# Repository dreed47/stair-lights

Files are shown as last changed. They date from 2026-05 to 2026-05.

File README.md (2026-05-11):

# Smart Staircase Lighting

DIY staircase lighting with capacitive touch detection and Home Assistant integration. Touch the handrail → lights fade in. Walk away → lights fade out. All settings tunable live via HA sliders.

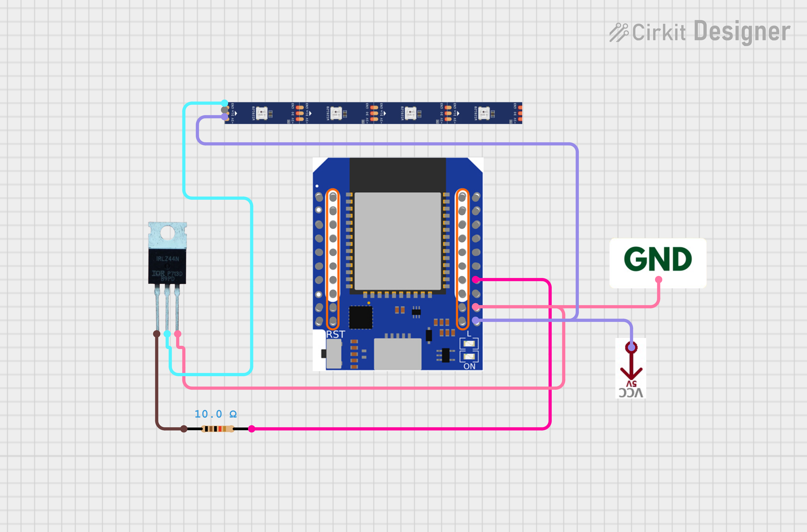
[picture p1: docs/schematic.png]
Wiring Schematic


---

## How It Works

1. Copper tape runs along the underside of the handrail, wired to **GPIO1** on the ESP32-S2 Mini as a capacitive touch sensor.
2. Touch triggers `handle_stair_timer` — a configurable filter-on delay confirms it's a real touch (not noise).
3. **GPIO18** drives an **IRLZ44N MOSFET** via PWM, which powers a **COB LED strip** with a smooth 1-second fade-in.
4. After the configured duration, lights fade out over 4 seconds.
5. Touching again during the timer restarts it (script `mode: restart`).

The COB strip gives a seamless "dot-less" glow. All wiring is routed internally through the wall with low-profile silicone grommets — hardware stays invisible.

---

## Hardware

| Component | Details |
| --- | --- |
| MCU | Wemos S2 Mini (ESP32-S2) |
| MOSFET | IRLZ44N (logic-level, TO-220) |
| LED Strip | COB (chip-on-board), single color |
| Touch Sensor | Copper tape on handrail → GPIO1 |
| PWM Output | GPIO18 → MOSFET gate |
| PCB | Custom KiCad design (see `hardware/kicad/`) |

ESP32-S2 Mini front
ESP32-S2 Mini pinout

---

## Firmware

Built with [ESPHome](https://esphome.io). No custom C++ — pure YAML.

### Flash

```bash
# Install ESPHome if needed
pip install esphome

# Add WiFi credentials
cp firmware/secrets.yaml.example firmware/secrets.yaml
# edit firmware/secrets.yaml with your SSID and password

# Flash
esphome run firmware/stairlights.yaml
```

`secrets.yaml` format:

```yaml
wifi_ssid: "YourNetwork"
wifi_password: "YourPassword"
```

After first flash, OTA updates work over WiFi — no USB needed.

---

## Home Assistant Controls

Once the ESPHome integration is added in HA, five sliders appear:

| Slider | Range | Default | Purpose |
| --- | --- | --- | --- |
| **Light Duration** | 5–120 s | 30 s | How long lights stay on after touch |
| **LED Brightness** | 10–100 % | 100 % | Peak brightness at fade-in |
| **Touch Threshold** | 1,000–300,000 | 50,000 | Capacitive trigger level — tune for your handrail |
| **Touch Filter On** | 0–100 ms | 8 ms | Debounce delay before turning on (rejects noise) |
| **Touch Filter Off** | 0–100 ms | 50 ms | Extra hang time before starting fade-out |

**Calibrating touch sensitivity:** Start with Touch Threshold at 50,000. Watch the `Staircase Touch Pad` binary sensor in HA. Raise the threshold if lights trigger from ambient noise/humidity; lower it if touches aren't registering.

---

## Wiring

See `docs/schematic.png` for the full Cirkit Designer diagram. Key connections:

```text
ESP32-S2 GPIO18  →  IRLZ44N Gate (via 10Ω resistor)
IRLZ44N Drain   →  LED Strip negative
LED Strip +     →  12V supply
IRLZ44N Source  →  GND
ESP32-S2 GPIO1  →  Copper tape (touch sensor)
ESP32-S2 GND   →  GND
ESP32-S2 3.3V  →  (internal, no external connection needed)
```

---

## File Structure

```text
stair-lights/
├── firmware/
│   └── stairlights.yaml        # ESPHome configuration
├── hardware/
│   ├── kicad/                  # KiCad schematic and PCB layout
│   │   ├── StairLights.kicad_pcb
│   │   ├── StairLights.kicad_pro
│   │   ├── StairLights.kicad_prl
│   │   └── StairLights.kicad_sch
│   ├── gerbers/
│   │   └── StairLights.kicad_pcb.zip   # Fabrication-ready Gerbers
│   └── stairs-pcb.step         # 3D model
└── docs/
    ├── schematic.png            # Wiring diagram
    ├── esp32-s2-mini-front.png  # MCU reference photo
    └── esp32-s2-mini-back.png   # MCU pinout
```

---

## Troubleshooting

**Lights trigger randomly** — Capacitive drift from humidity or power fluctuations. Raise Touch Threshold or increase Touch Filter On delay.

**Touch not registering** — Lower Touch Threshold. Ensure copper tape has good contact with the GPIO1 wire.

**Fallback AP** — If WiFi is unreachable, the ESP32 broadcasts `Stairlights Fallback Hotspot`. Connect to it and navigate to `192.168.4.1` to reconfigure.

**OTA fails** — Make sure `secrets.yaml` OTA password matches what was flashed. Default is in the YAML.

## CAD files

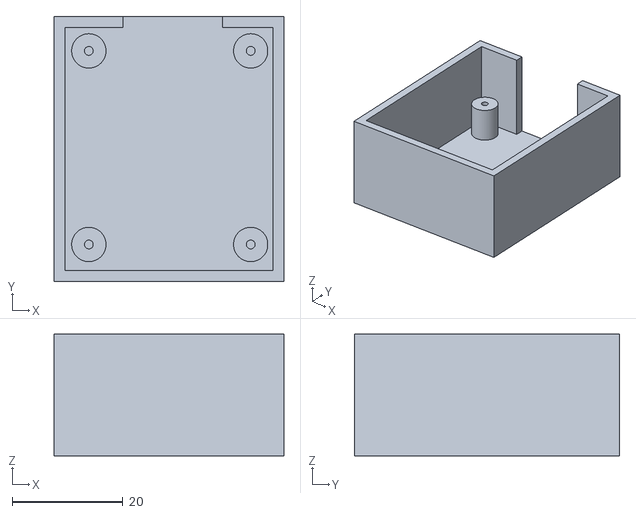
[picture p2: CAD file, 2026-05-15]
hardware/case-bottom.stl
41.5 x 47.9 x 22.0

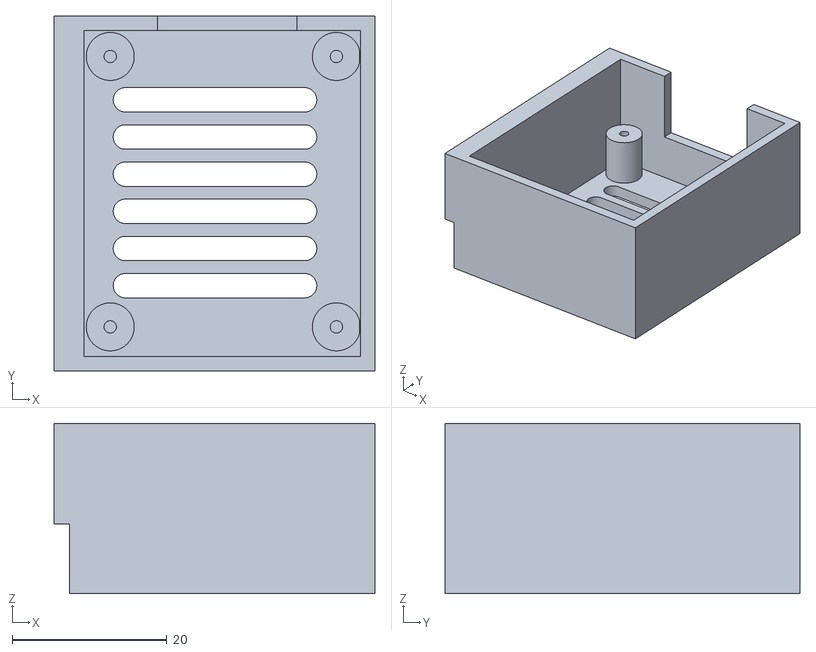
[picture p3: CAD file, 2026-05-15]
hardware/base.stl
41.4 x 45.9 x 22.0

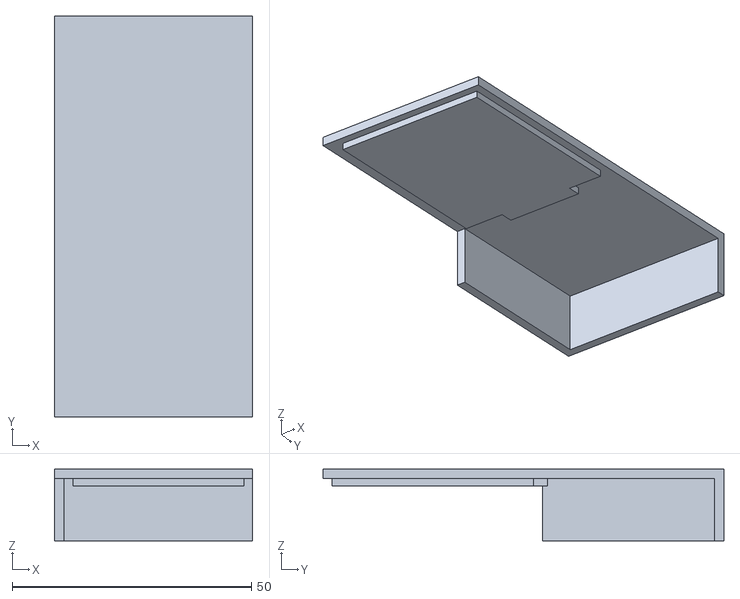
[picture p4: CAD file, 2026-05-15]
hardware/lid.stl
41.4 x 83.9 x 15.0

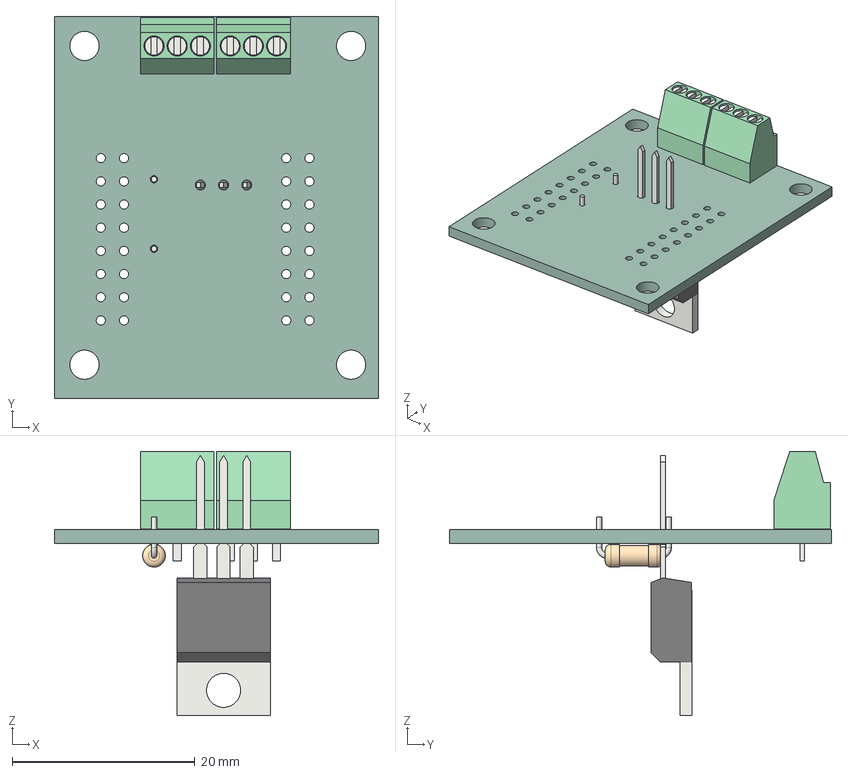
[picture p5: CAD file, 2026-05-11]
hardware/stairs-pcb.step
35.5 x 41.9 x 29.0 mm
TerminalBlock_Phoenix_MPT-0,5-3-2.54_1x03_P2.54mm_Horizontal x 2
TO-220-3_Vertical
R_Axial_DIN0207_L6.3mm_D2.5mm_P7.62mm_Horizontal
StairLights_PCB

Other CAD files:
hardware/base v2.stl

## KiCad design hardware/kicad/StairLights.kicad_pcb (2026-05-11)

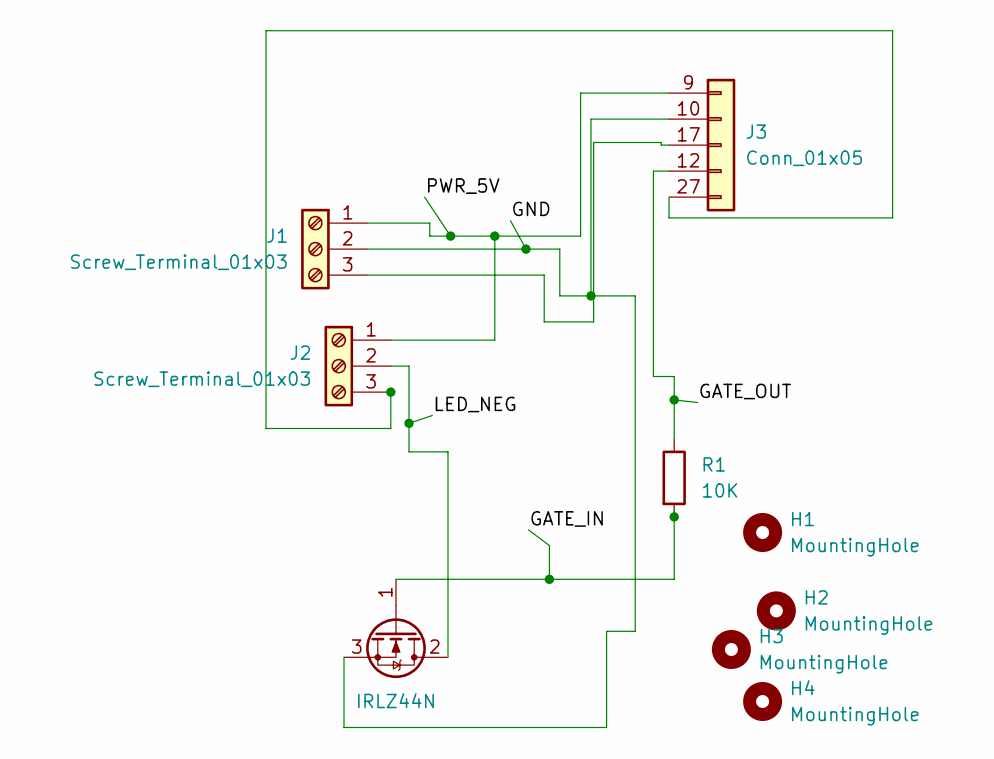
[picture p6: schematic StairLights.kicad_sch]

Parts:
H1, H2, H3, H4: MountingHole; MountingHole_3.2mm_M3
J1, J2: Screw_Terminal_01x03; TerminalBlock_Phoenix_MPT-0,5-3-2.54_1x03_P2.54mm_Horizontal
J3: Conn_01x05; wemoss2
Q1: IRLZ44N; TO-220-3_Vertical
R1: 10K; R_Axial_DIN0207_L6.3mm_D2.5mm_P7.62mm_Horizontal

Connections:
/GATE_IN: Q1.1 (G), R1.2
/GATE_OUT: J3.12, R1.1
/GND: J1.2, J3.10, Q1.3 (S)
/LED_NEG: J2.2, Q1.2 (D)
/PWR_5V: J1.1, J2.1, J3.9
unnamed: J1.3, J3.17
unnamed: J2.3, J3.27

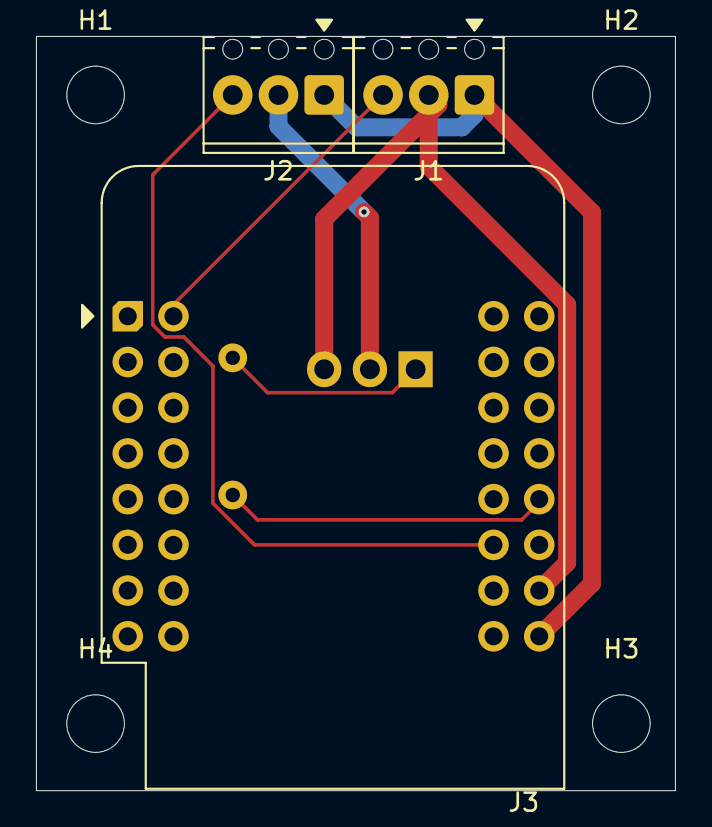
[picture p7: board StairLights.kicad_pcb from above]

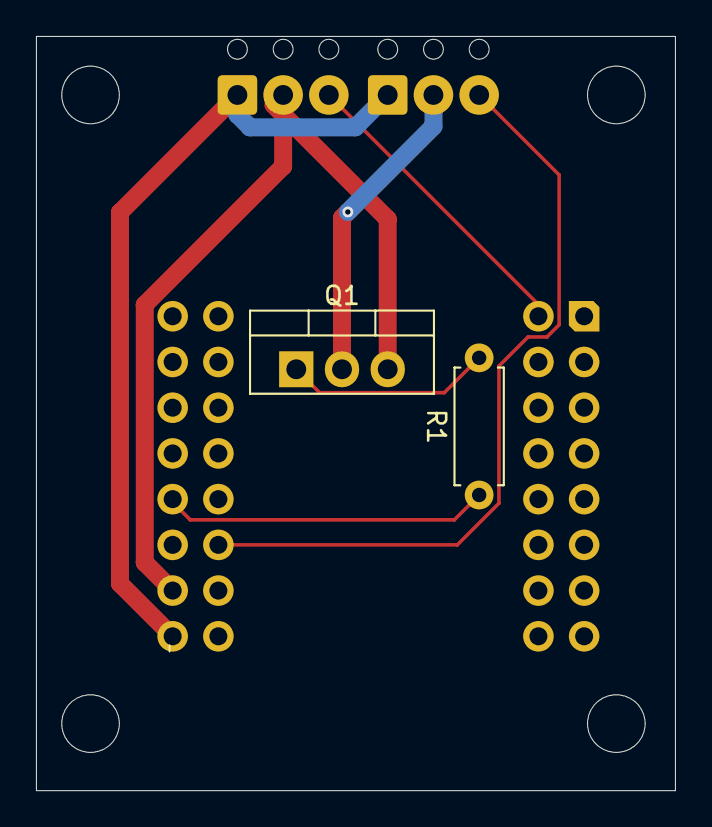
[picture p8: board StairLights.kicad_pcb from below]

Board: 2 copper layers, 35.5 x 41.9 mm, 9 parts (2 on the bottom side), 7 nets.

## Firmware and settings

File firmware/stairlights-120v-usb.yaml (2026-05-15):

globals:
  - id: last_touch_time
    type: unsigned long
    initial_value: '0'
    restore_value: no
  - id: touch_cooldown_ms
    type: int
    initial_value: '6000'  # 6 second cooldown - covers the full power bounce
    restore_value: no

esphome:
  name: stairlights
  friendly_name: StairLights

esp32:
  board: lolin_s2_mini
  framework:
    type: arduino

esp32_touch:
  setup_mode: false
  measurement_duration: 1ms   
  sleep_duration: 0.5ms     
  

logger:
  level: INFO
  #logs:
  #  esp32_touch: ERROR

api:
  encryption:
    key: "APZrHqoNUsUds0Yg1z2ZE0pQV3Ka5jZInQDgnXsFt8E="

ota:
  - platform: esphome
    password: "c4cd1166b0949847f0890fbffeeb403f"

wifi:
  ssid: !secret wifi_ssid
  password: !secret wifi_password
  ap:
    ssid: "Stairlights Fallback Hotspot"
    password: "02FUenUi5wo2"

captive_portal: 

# ============================================================
# HOME ASSISTANT CONTROLLABLE SETTINGS
# ============================================================

number:
  - platform: template
    name: "Staircase Light Duration"
    id: light_duration
    icon: "mdi:timer-outline"
    unit_of_measurement: "seconds"
    min_value: 5
    max_value: 120
    step: 5
    initial_value: 30
    optimistic: true
    restore_value: true
    mode: slider

  - platform: template
    name: "Staircase LED Brightness"
    id: led_brightness
    icon: "mdi:brightness-5"
    unit_of_measurement: "%"
    min_value: 10
    max_value: 100
    step: 5
    initial_value: 100
    optimistic: true
    restore_value: true
    mode: slider

  - platform: template
    name: "Touch Threshold"
    id: touch_threshold_ui
    icon: "mdi:target-variant"
    min_value: 10000
    max_value: 500000      
    step: 5000
    initial_value: 180000  # Hardcoded default above the 149k power bounce
    optimistic: true
    mode: slider      
    on_value:
      then:
        - lambda: 'id(stair_touch).set_threshold(x);'


  - platform: template
    name: "Touch Filter On"
    id: touch_filter_on
    icon: "mdi:clock-start"
    unit_of_measurement: "ms"
    min_value: 0
    max_value: 100
    step: 1
    initial_value: 8
    optimistic: true
    mode: slider     

  - platform: template
    name: "Touch Filter Off"
    id: touch_filter_off
    icon: "mdi:clock-end"
    unit_of_measurement: "ms"
    min_value: 0
    max_value: 100
    step: 1
    initial_value: 50
    optimistic: true
    mode: slider     

# ============================================================
# OUTPUT & LIGHT
# ============================================================

output:
  - platform: ledc
    pin: GPIO18
    id: mosfet_pwm
    frequency: 1000Hz

light:
  - platform: monochromatic
    name: "Staircase LEDs"
    output: mosfet_pwm
    id: stair_leds

# ============================================================
# LOGIC SCRIPT (With Power Supply Settle Lockout)
# ============================================================
script:
  - id: handle_stair_timer
    mode: restart  
    then:
      - delay: !lambda "return id(touch_filter_on).state;"
      
      - if:
          condition:
            binary_sensor.is_on: stair_touch
          then:
            - light.turn_on:
                id: stair_leds
                transition_length: 1s 
                brightness: !lambda "return id(led_brightness).state / 100.0;"
            
            - delay: !lambda "return id(light_duration).state * 1000;"
            
            - light.turn_off:
                id: stair_leds
                transition_length: 4s

# ============================================================
# TOUCH SENSOR
# ============================================================

binary_sensor:
  - platform: esp32_touch
    name: "Staircase Touch Pad"
    id: stair_touch
    pin: GPIO1
    threshold: 180000
    on_press:
      then:
        - lambda: |-
            unsigned long now = millis();
            // Only trigger if cooldown has expired
            if (now - id(last_touch_time) >= id(touch_cooldown_ms)) {
              id(last_touch_time) = now;
              id(handle_stair_timer).execute();
            }
            else {
              ESP_LOGD("cooldown", "Touch ignored - cooldown active (%lu ms remaining)", 
                       id(touch_cooldown_ms) - (now - id(last_touch_time)));
            }

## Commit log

2026-05-11 first test on handrail - working
    [stairs-pcb.step]
2026-05-11 Update .gitignore to ignore .hosrty folder and KiCad backups
2026-05-11 added docs
    [StairLights.kicad_pcb, StairLights.kicad_sch, stairs-pcb.step]
